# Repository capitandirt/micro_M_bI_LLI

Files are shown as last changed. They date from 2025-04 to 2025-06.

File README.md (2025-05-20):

# *MICROMOUSE WITH USING* C++
  Или же по-старославянски **micro_M_bI_LLI**

## Авторы ПО:

1. [**Capitandirt**](https://github.com/capitandirt)
      
2. [**Denzov**](https://github.com/denzov)

## Главная сводка по micro maze'у
1. Лабиринт N-ого размера (в нашем случае 11x11)
2. Клетка размером 18x18 см
3. Робот ограничен размером 16.8x16.8 см
4. Старт в угловой клетке
5. Финиш в центре

## Основа робота
Конструктив робота взят с [ukrmars](https://github.com/ukmars/ukmarsbot/tree/master)

## Основы терминологии проекта
### Всё, что связано с обозначением передвижения в клетке
| Термин | Что имеется в виду |
|---|---|
| Direction | Направление стороны (nort, west, south, east), в которую совершится действие в лабиринте. |
| Primitive | Обозначает абстрактное действие поворота или движения в клетке лабиринта. Отличает от direction его относительностью от робота. |
| Smart (Циклограмма) | Обозначает действие поворота или движения в клетке лабиринта. Отличает от primitive конкретной реализацией. |
### Хранение данных на МК
#### class Maze
*О том, как представлено хранение лабиринта в памяти посредством структуры RawCellStore.*
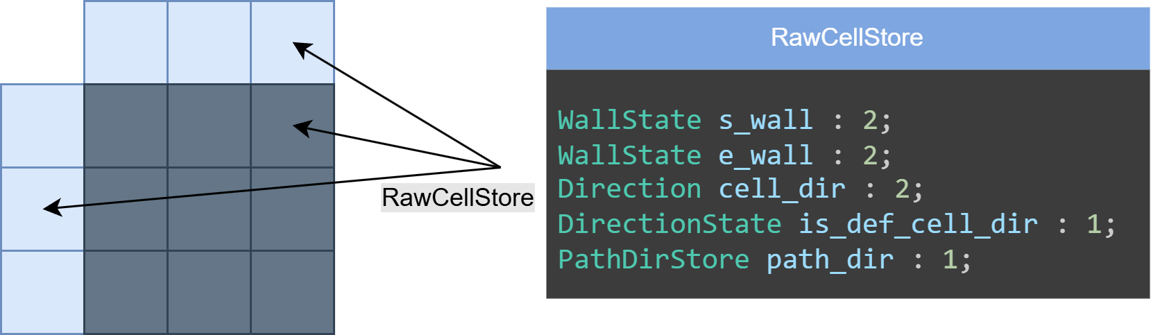
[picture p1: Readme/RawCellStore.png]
RawCellStore

Элемент ячейки общего буффера ```_cell_blocks[MAZE_MEM_SIZE]``` — ```RawCellStore```, занимает 1 байт. Таким образом ```_cell_blocks``` размером MAZE_MEM_SIZE байт. Значение ```MAZE_MEM_SIZE``` определяется размером (N) лабиринта, однако не равно N. Если быть точным ```MAZE_MEM_SIZE = Nx2 + NxN```. Здесь ```NxN``` — "основные" ячейки лабиринта (отмечены темным на картинке), ```Nx2``` — "побочные" или, можно сказать, "фантомные" (отмечены ярко голубым); такие побочные ячейки необходимы, чтобы задавать боковые (западные и северные) стороны лабиринта.
Для того, чтобы понять, что здесь происходит, рассмотрим структуру RawCellStore с битовыми полями:
  1. *s_/e_wall*. Для построения всего лабиринта необходимо лишь сохранять состояние (```HI, LO```) южной и восточной стенки *клетки*.
  2. *cell_dir*. Это битовое поле отвечает за хранение направлений в итоговом пути для лабиринта в каждой ячейке.
  3. *is_def_cell_dir*. Поле отвечает определено ли *cell_dir*.
  4. *path_dir*. Поле отвечает за хранение направлений утогового пути решенного лабиринта. Есть нюанс: все битовые поля, исключая ```path_dir```, занимают 7 бит, однако для хранения Direction необходимо 2 бита (4 направления). Чтобы RawCellStore занимал не более байта, пришлось делать трюк: итогове значение ```path_dir``` складывается от 2 элементов буффера ```_cell_blocks```, как бы разделясь на старшую и младщую часть.

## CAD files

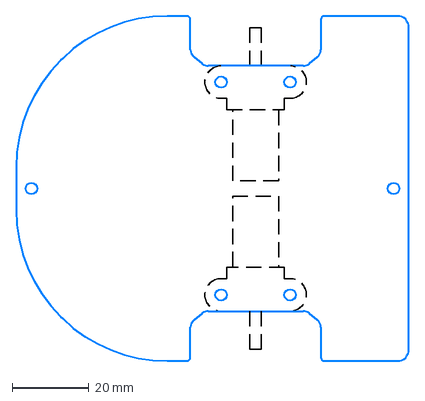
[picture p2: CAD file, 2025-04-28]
Board/main/out/board_contour.dxf
102.5 x 90.0 mm

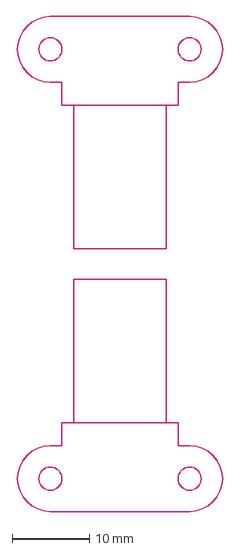
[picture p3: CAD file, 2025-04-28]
Board/main/out/board_contour_for_motors.dxf
26.5 x 64.0 mm

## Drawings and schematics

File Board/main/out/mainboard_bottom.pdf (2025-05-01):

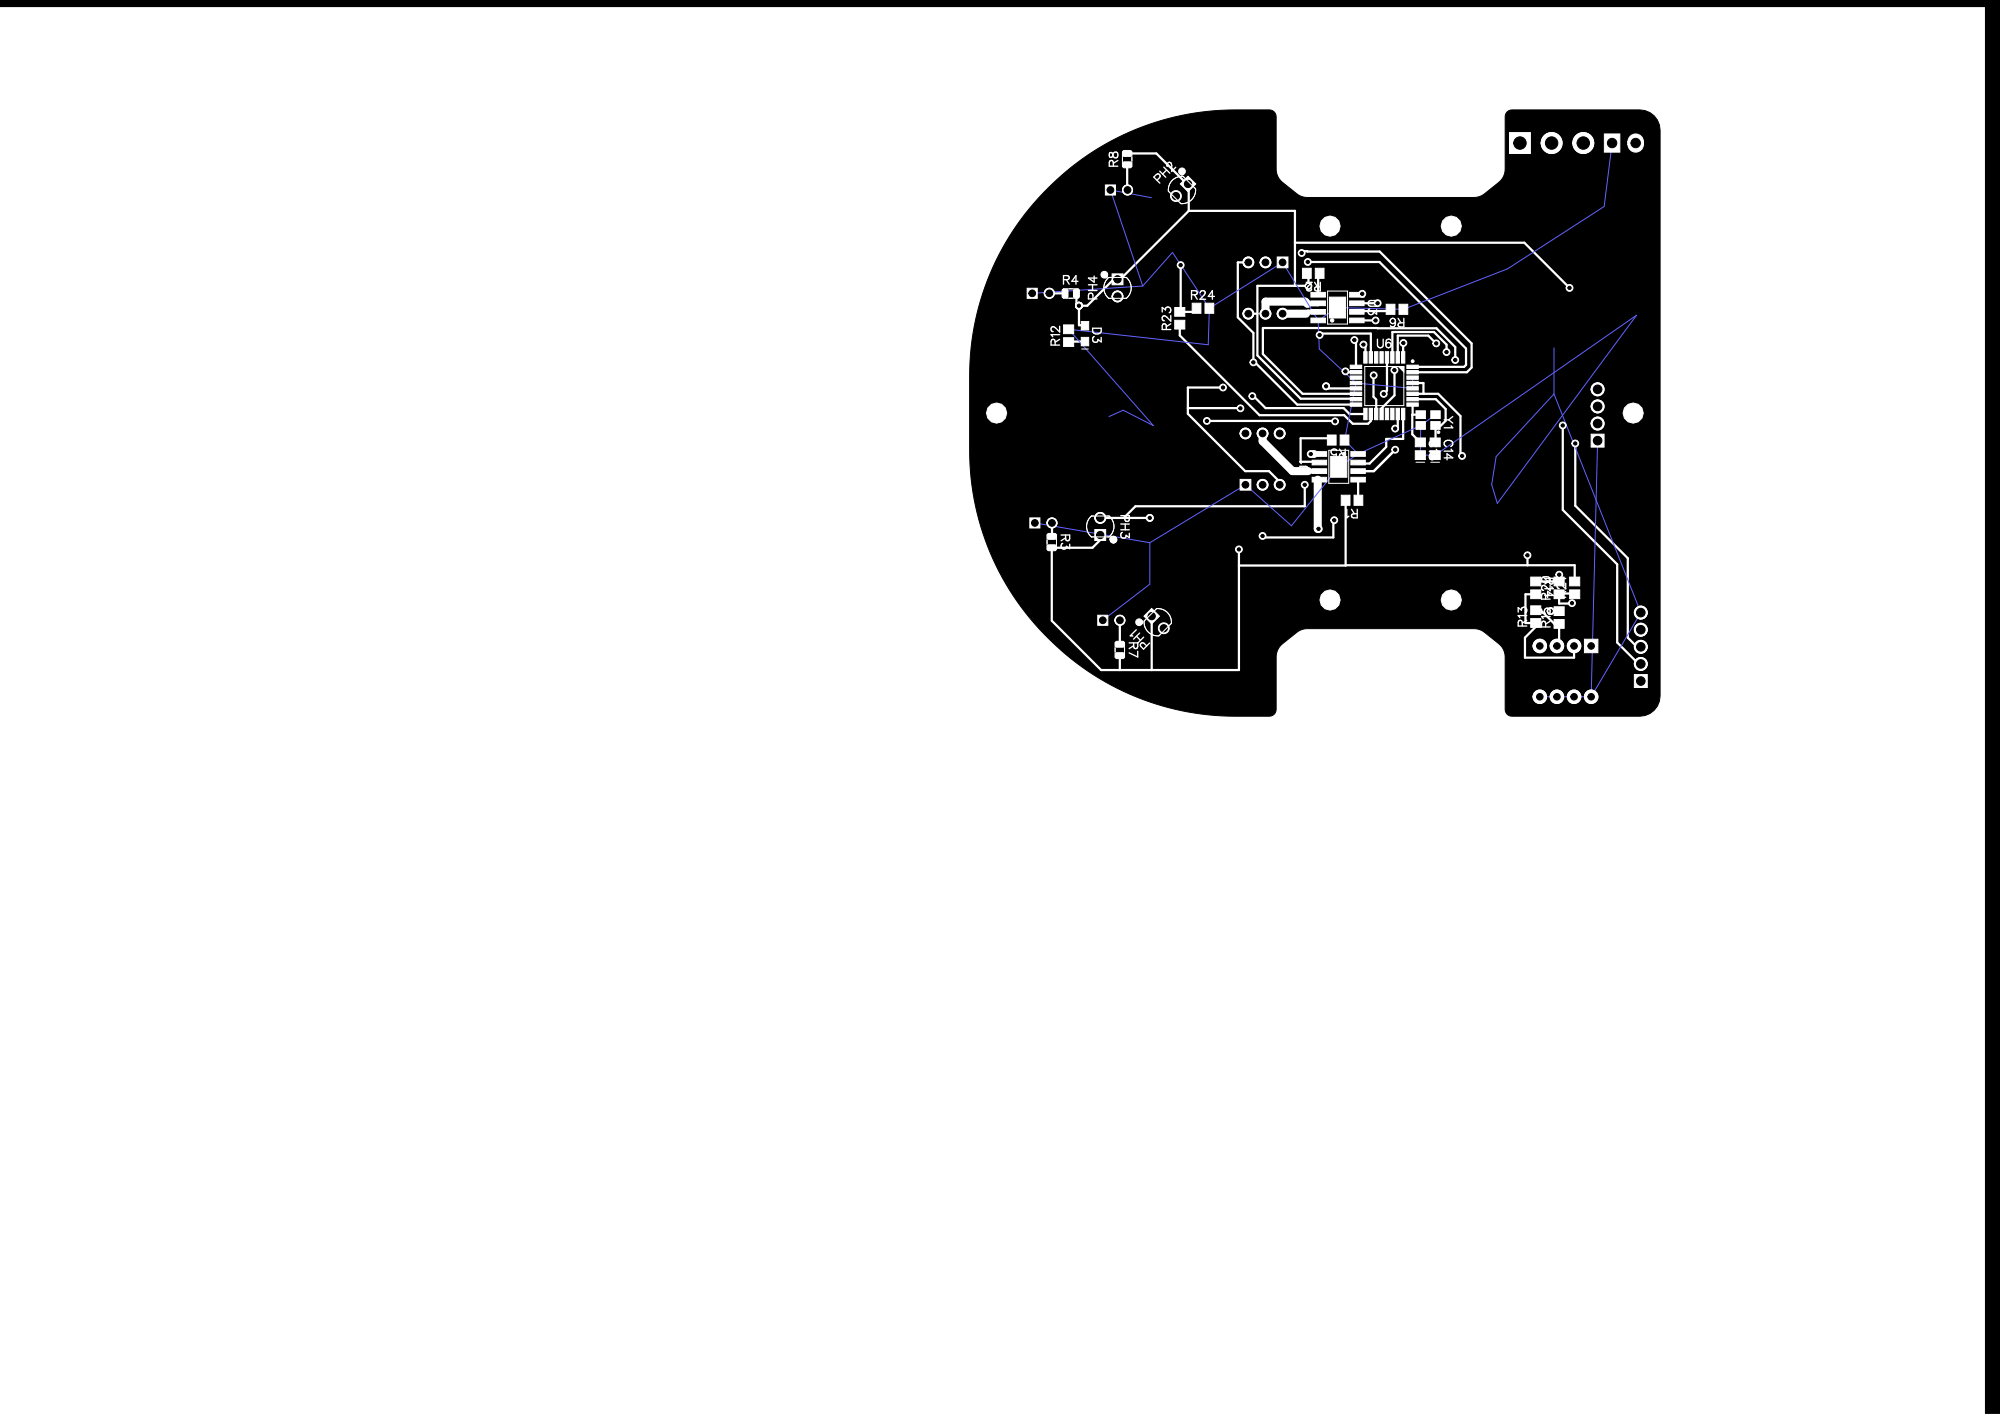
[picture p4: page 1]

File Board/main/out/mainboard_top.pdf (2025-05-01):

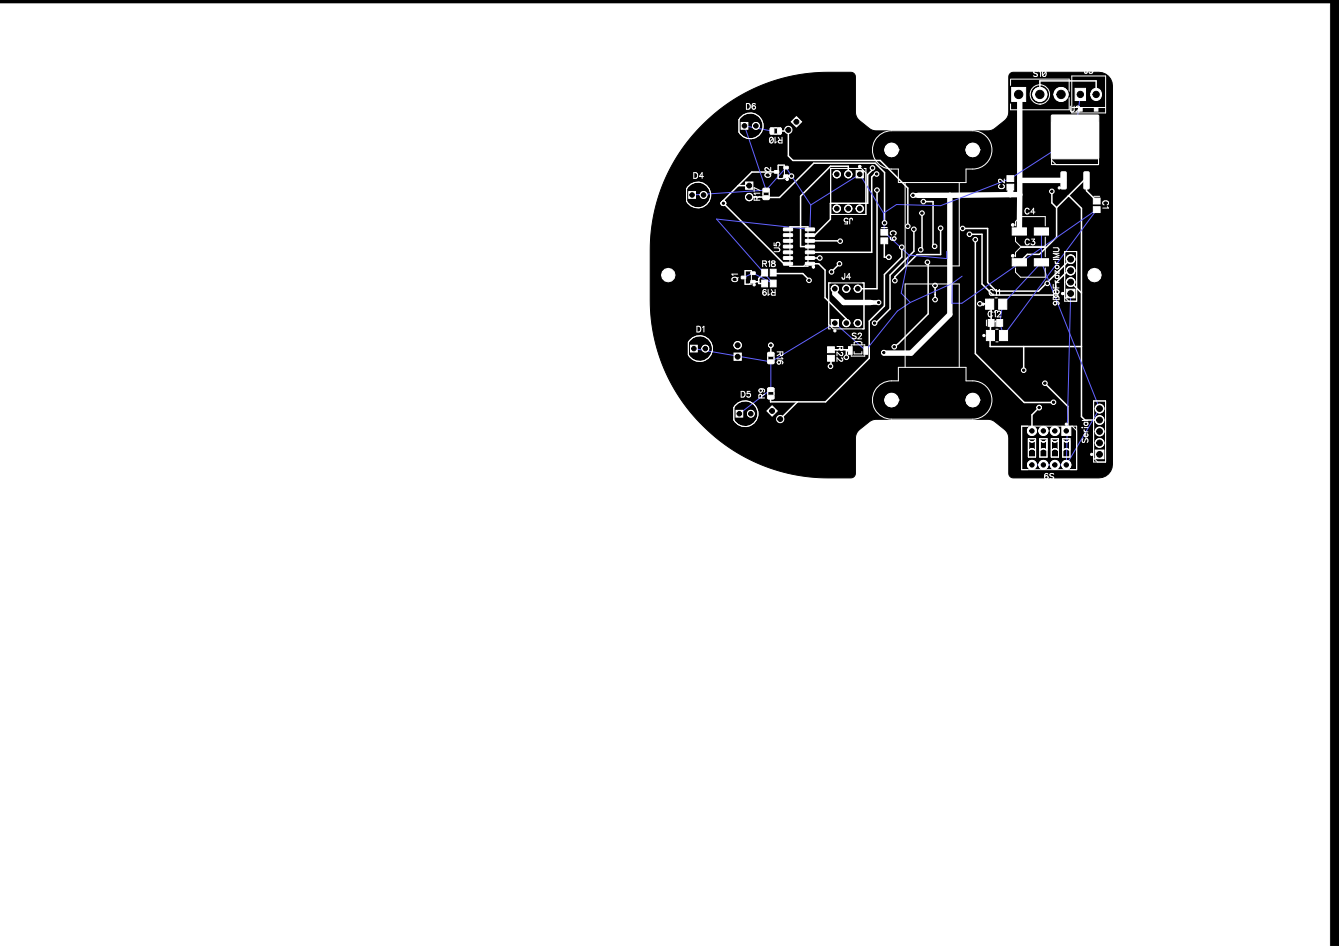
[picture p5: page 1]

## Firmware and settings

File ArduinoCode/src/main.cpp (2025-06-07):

#include <Arduino.h>
#include "Devices.h"
#include "DevicesMethods.h"

void setup()
{
    DEVICES::TEST::SET_SERIAL();
    DEVICES::INIT();

    delay(25); // ставлю delay чтобы датчики успели прочитать значение хотя бы раз
    optocoupler.setStaticError();
}

void loop(){
    static uint32_t last_time = 0;
    while(micros() - last_time < Ts_us)
        ;
    last_time = micros();
    
    DEVICES::TICK(last_time / 1000);

    cycloWorker.doCyclogram();
    robot.stateMachine();
    cycloWorker.tryComplete();
}

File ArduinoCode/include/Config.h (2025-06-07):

#ifndef _CONFIG_H_
#define _CONFIG_H_

/*==GLOBAL SERIAL SHUT DEFINE BEGIN==*/
#define GLOBAL_OUTPUT 0
#if GLOBAL_OUTPUT

#define PRINT(x) Serial.print(x)
#define PRINTLN(x) Serial.println(x)

#else

#define PRINT(x)
#define PRINTLN(x)

#endif
/*==GLOBAL SERIAL SHUT DEFINE END==*/

/*==UTILITY DEFINES BEGIN==*/
#define MAX_ANALOG_VALUE static_cast<int32_t>(1023)
#define HALF(x)  ((x) / 2)
/*==UITILITY DEFINES END==*/

/*==FREQUENCY DISCRETIZATION BEGIN==*/
#define Ts_us 10000 // 0 < Ts_us <= 10000
#define Ts_s (Ts_us / 1000000.0)
/*==FREQUENCY DISCRETIZATION END==*/

/*==ENCODER CONNECTION PINS BEGIN==*/
#define LEFT_CLK_A_PIN 2
#define LEFT_B_PIN 4
#define LEFT_ENC_DIR -1

#define RIGHT_CLK_A_PIN 3
#define RIGHT_B_PIN 5
#define RIGHT_ENC_DIR 1
/*==ENCODER CONNECTION PINS END==*/

/*==ROBOT PARAMS BEGIN==*/
#define ROBOT_WIDTH 0.072f
#define WHEEL_RADIUS 0.01725f
/*==ROBOT PARAMS END*/

/*==WHEELS PARAMS BEGIN==*/
#define ENC_PPR 48
#define GEAR_RATIO 30
#define TICK2RAD (2.f * M_PI / (ENC_PPR * GEAR_RATIO))
/*==WHEELS PARAMS END==*/

/*==MOTOR PINS BEGIN==*/
#define LEFT_MOTOR_DIR 7
#define LEFT_MOTOR_PWM 9
#define LEFT_MOTOR_POLARITY 1

#define RIGHT_MOTOR_DIR 8
#define RIGHT_MOTOR_PWM 10
#define RIGHT_MOTOR_POLARITY 0
/*==MOTOR PINS END==*/

/*==FUNCTIONAL SELECTOR BEGIN==*/
#define INDICATOR_LED_PIN (6)
#define FUNCTION_PIN A6
/*==FUNCTIONAL SELECTOR END==*/

/*==W MOTOT PIREG BEGIN==*/
#define W_K_MOTOR (6 / 1.5) //он выдаёт примерно 6.5 рад/с на 1.5 Волта
#define W_T_MOTOR 0.15
#define W_T_u (2 * Ts_s)

#define W_KP (0.4f) // Kp = K
#define W_KI (W_KP / 0.05f) // Ki = K / T
/*==W MOTOT PIREG END==*/

/*==MAZE BEGIN==*/
// MY MAZE STRUCT
// for exapmle, let's take maze 3x3:
//        X - a x i s 
//      Y      === === ===
//      |     | 0 | 1 | 2 |
//      a  === === === ===
//      x | 3 | 4 | 5 | 6 |
//      i  === === === ===
//      s | 7 | 8 | 9 | 10|
//         === === === ===
//        | 11| 12| 13| 14|
//         === === === ===
// here 0, 1, 2, 3, 7, 11 cells are utility. important for west and north fronts of maze
// total number of cells are 15, but informal numbers of cells are 9 (3x3)

#define MAZE_SIDE_LENGTH 11

#define MAZE_SIDE_LENGTH_ADD_ONE (MAZE_SIDE_LENGTH + 1)
#define MAZE_TOTAL_SIZE (MAZE_SIDE_LENGTH * 2 + MAZE_SIDE_LENGTH * MAZE_SIDE_LENGTH)
#define MAZE_MEM_SIZE (((MAZE_SIDE_LENGTH + MAZE_SIDE_LENGTH) + MAZE_SIDE_LENGTH * MAZE_SIDE_LENGTH))

#define MAZE_PATH_SIZE ((MAZE_TOTAL_SIZE - (MAZE_TOTAL_SIZE % 2)))
/*==MAZE END==*/

/*==QUEUE BEGIN==*/
#define MAX_SIZE_QUEUE (MAZE_SIDE_LENGTH * 4)
/*==QUEUE END*/


/*==ROBOT START PLACE BEGIN==*/
#define START_ROBOT_COORDS {0, 0}
/*==ROBOT START PLACE END==*/


/*==ROBOT FINISH PLACE BEGIN==*/
#define FINISH_ROBOT_COORDS_X (2)
#define FINISH_ROBOT_COORDS_Y (2)

#define FINISH_ROBOT_COORDS {FINISH_ROBOT_COORDS_X, FINISH_ROBOT_COORDS_Y}
/*==ROBOT FINISH PLACE END==*/

/*==CHECK TEST'S CORRECT OUTPUT BEGIN==*/
/*
---[ IN TEST CYCLOGRAMS: 
    \--Primitive:
        | BLANK FORWARD LEFT RIGHT STOP 
    \--Smarts: 
        | IDLE FWD1 SS90SL SS90SR STOP
    ]
---[ IN TEST BFS PATH EQUAL:
    \--| S E N E E E E S S W W S E S E S
    ]
---[ IN TEST CONVERT_PATH_TO_CYCLOGRAM:
    \--|
    IP180 FWD_HALF SS90EL SS90EL SS90ER FWD1 FWD1 FWD1 SS90ER FWD1 SS90ER FWD1 SS90EL SS90EL SS90ER SS90EL SS90ER FWD_HALF STOP
    ]
*/
/*==CHECK TEST'S CORRECT OUTPUT END==*/

/*==OPTOCOUPLER BEGIN==*/
#define OPTOCOUPLER_EMITERS_A (11)
#define OPTOCOUPLER_EMITERS_B (12)

#define OPTOCOUPLER_SENSOR_0 (14)
#define OPTOCOUPLER_SENSOR_1 (15)
#define OPTOCOUPLER_SENSOR_2 (16)
#define OPTOCOUPLER_SENSOR_3 (17)
#define OPTOCOUPLER_SENSOR_4 (18)

#define OPTOCOUPLER_SENSE_ERROR (35)
#define OPTOCOUPLER_SENSE_THRESHOLD_LEFT (50)
#define OPTOCOUPLER_SENSE_THRESHOLD_FWD_L (40)
#define OPTOCOUPLER_SENSE_THRESHOLD_FWD_R (40)
#define OPTOCOUPLER_SENSE_THRESHOLD_RIGHT (50)
/*==OPTOCOUPLER END==*/

/*==BATTERY BEGIN==*/
#define BATTERY_PIN (A7)
/*==BATTERY END==*/

#endif // !_CONFIG_H_

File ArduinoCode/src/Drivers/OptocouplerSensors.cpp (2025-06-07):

#include "Drivers/OptocouplerSensors.h"

void OptocouplerSensors::init(){
    bitClear(ADCSRA, ADPS0);
    bitClear(ADCSRA, ADPS1);
    bitSet(ADCSRA, ADPS2);

    pinMode(EMITERS_FWD, OUTPUT);
    pinMode(EMITERS_SIDE, OUTPUT);
    pinMode(REC_RIGHT, INPUT);
    pinMode(REC_LEFT, INPUT);
    pinMode(REC_FWD_LEFT, INPUT);
    pinMode(REC_FWD_RIGHT, INPUT);
}

void OptocouplerSensors::tick(){
    // dark read
    static int16_t cur_dark_right = 0;
    cur_dark_right = analogRead(REC_RIGHT);

    if(abs(cur_dark_right - dark_sense.right) < 100){
        dark_sense.right = cur_dark_right;
    }

    dark_sense.left      = analogRead(REC_LEFT);
    dark_sense.forward_l = analogRead(REC_FWD_LEFT);
    dark_sense.forward_r = analogRead(REC_FWD_RIGHT);

    digitalWrite(EMITERS_FWD, 1);
    digitalWrite(EMITERS_SIDE, 1);

    delayMicroseconds(50);

    // light read
    CAN_GET_SENSE = 0;

    // _sense[OptocouplerSense::From::RIGHT] += 
    //     (analogRead(REC_RIGHT) - dark_sense.right - _sense[OptocouplerSense::From::RIGHT]) * K_F;

    // _sense[OptocouplerSense::From::LEFT] +=
    //     (analogRead(REC_LEFT) - dark_sense.left - _sense[OptocouplerSense::From::LEFT]) * K_F;

    // _sense[OptocouplerSense::From::FORWARD_L] +=
    //     (analogRead(REC_FWD_LEFT)  - dark_sense.forward_l - _sense[OptocouplerSense::From::FORWARD_L]) * K_F;

    // _sense[OptocouplerSense::From::FORWARD_R] +=
    //     (analogRead(REC_FWD_RIGHT) - dark_sense.forward_r - _sense[OptocouplerSense::From::FORWARD_R]) * K_F;

    _sense[OptocouplerSense::From::RIGHT] = analogRead(REC_RIGHT) - dark_sense.right;
    _sense[OptocouplerSense::From::LEFT]  = analogRead(REC_LEFT)  - dark_sense.left;

    _sense[OptocouplerSense::From::FORWARD_L] = analogRead(REC_FWD_LEFT)  - dark_sense.forward_l;
    _sense[OptocouplerSense::From::FORWARD_R] = analogRead(REC_FWD_RIGHT) - dark_sense.forward_r;

    CAN_GET_SENSE = 1;

    digitalWrite(EMITERS_FWD, 0);
    digitalWrite(EMITERS_SIDE, 0);
}

void OptocouplerSensors::calc(){
    calc_sense_mask();
    calc_relative_cell();
}

Sense_t OptocouplerSensors::getSense() const{
    while(!CAN_GET_SENSE)
        ;

    return _sense.get();
}

Cell OptocouplerSensors::getRelativeCell() const{
    return _relative_cell;
}
Cell OptocouplerSensors::getCell(Direction robot_dir) const{
    Cell cell_from_sense = inDir(_relative_cell, robot_dir);

    return cell_from_sense;
}

void OptocouplerSensors::printAbsCell() const{
    Serial.print((int)_relative_cell.north_wall);
    Serial.print(" ");
    Serial.print((int)_relative_cell.east_wall);
    Serial.print(" ");
    Serial.print((int)_relative_cell.south_wall);
    Serial.print(" ");
    Serial.println((int)_relative_cell.west_wall);
}

void OptocouplerSensors::printMask() const{
    Serial.println( String(_sense_mask.left) + " " + 
                    String(_sense_mask.forward_l) + " " +
                    String(_sense_mask.forward_r) + " " + 
                    String(_sense_mask.right));
}

void OptocouplerSensors::printSense() const{
    while (!CAN_GET_SENSE)
        ;    

    Serial.println( String(_sense.get().left) + " " + 
                    String(_sense.get().forward_l) + " " +
                    String(_sense.get().forward_r) + " " + 
                    String(_sense.get().right));
}

void OptocouplerSensors::calc_sense_mask(){
    _sense_mask.forward_l = _sense[OptocouplerSense::From::FORWARD_L] > SENSE_THRESHOLD_FWD_L;
    _sense_mask.forward_r = _sense[OptocouplerSense::From::FORWARD_R] > SENSE_THRESHOLD_FWD_R;
    _sense_mask.left      = _sense[OptocouplerSense::From::LEFT] > SENSE_THRESHOLD_LEFT;
    _sense_mask.right     = _sense[OptocouplerSense::From::RIGHT] > SENSE_THRESHOLD_RIGHT;
}

void OptocouplerSensors::calc_relative_cell(){
    _relative_cell.north_wall = toWallState(_sense_mask.forward_l || _sense_mask.forward_r);
    _relative_cell.east_wall  = toWallState(_sense_mask.right);
    _relative_cell.west_wall  = toWallState(_sense_mask.left);
    _relative_cell.south_wall = toWallState(false);
}

void OptocouplerSensors::setStaticError()
{
    _static_err = _sense.get().right - _sense.get().left;
}
int16_t OptocouplerSensors::getStaticError() const
{
    return _static_err;
}


int16_t OptocouplerSensors::getLeftTreshold() const
{
    return SENSE_THRESHOLD_LEFT; 
}

int16_t OptocouplerSensors::getRightTreshold() const
{
    return SENSE_THRESHOLD_RIGHT; 
}

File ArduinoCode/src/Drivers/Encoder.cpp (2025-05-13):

#include "Drivers/Encoder.h"

void Encoder::init()
{
    pinMode(CLK_A_PIN, INPUT);
    pinMode(B_PIN, INPUT);

    noInterrupts();
    attachInterrupt(
        digitalPinToInterrupt(CLK_A_PIN),
        ISR,
        CHANGE
    );

    _ett[0b00][0b01] = ENC_DIR;
    _ett[0b01][0b11] = ENC_DIR;
    _ett[0b11][0b10] = ENC_DIR;
    _ett[0b10][0b00] = ENC_DIR;
    
    _ett[0b00][0b10] = -ENC_DIR;
    _ett[0b10][0b11] = -ENC_DIR;
    _ett[0b11][0b01] = -ENC_DIR;
    _ett[0b01][0b00] = -ENC_DIR;
    
    interrupts();
}

void Encoder::tick()
{
    noInterrupts();
    const int counter_inc = _counter;
    _counter = 0;
    interrupts();

    _dphi = counter_inc * TICK2RAD;
    _phi += _dphi;
}

void Encoder::isrCallback()
{
    const uint8_t B = digitalRead(B_PIN);
    const uint8_t CLK_A = digitalRead(CLK_A_PIN);
    const uint8_t A = CLK_A ^ B;
    const uint8_t enc = (A << 1) | B;

    _counter += _ett[_enc_old][enc];
    _enc_old = enc;
}

float Encoder::getPhi() const{
    return _phi;
}

float Encoder::getDPhi() const{
    return _dphi;
}

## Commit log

2025-04-16 первый коммит
    [M_bI_LLI_plate.PrjPcb]
2025-04-16 упс, вот теперь первы коммит
    [PCB1.PcbDoc]
2025-04-18 до конца соединили коды, сделали базу фладфила
2025-04-19 added convesion from maze ind to vec2 and in reverse
    [Config.h, Maze.cpp]
2025-04-20 added template of a plate
    [M_bI_LLI_plate.PrjPcb, PCB1.PcbDoc]
2025-04-23 completed schematic, started 3d plate view
2025-04-23 added prototype of mouse in 3d
2025-04-23 added the hole for the travois (тип `-` волокуша)
2025-04-24 minor changes in plate
2025-04-24 restructuring boards directories
    [board_contour.dxf]
2025-04-24 modified Board/.gitignore
2025-04-25 окончательное преобразование пути в поисковые циклограммы
2025-04-26 added timer interrupt fo tick devices
2025-04-26 changed getting robot primitives, timer interrupts are debugging now
2025-04-26 added pcb
2025-04-28 added optocoupler sense & worked with board
    [board_contour.dxf, board_contour_for_motors.dxf]
2025-04-28 added tim2 handler. completed interrupts. first realization of tick in optocoupler
2025-04-29 completed class Optocoupler. Flood fill works in theory. Changed odometry: getting maze coords and dirs from flood fill funcs
2025-04-29 board in process
2025-04-30 сделал первичную разводку платы
2025-04-30 мелкие фиксы
2025-04-30 добавил провреку на пройденную клетку в rawCellStore. не рабочий код - floodfill не аърабоатет
2025-05-01 fixed errors in pcb board
2025-05-01 pcb minor fix
2025-05-01 pcb minor fix 2
2025-05-02 исправил одометрию, сделал проверку на 135 градусов
    [Odometry.cpp]
2025-05-07 сделал первую версию регулятора по датчикам
2025-05-07 РАБОЧИЙ КОД ФЛАДФИЛА
    +рабочий регулятор по датчикам
2025-05-08 not workable back handler
    [Config.h, CycloStore.cpp, Cyclograms.h]
2025-05-09 нерабочий коммит, переход для мержа
2025-05-09 я написал (кажется) FWD_X
2025-05-10 промежуточны коммит, см описание
    циклограммы в отдельную папку, пару новых циклограмм, удалены следы плохого решения на FWD_X
2025-05-10 Сделал десяток новых циклограмм,
2025-05-10 напичал TO_DD90S, продолжил писать toSmart, но недописал
    также придумал и описал архитектуру toSmart, на которую перепишу её позже
2025-05-12 Продолжил писать convertToSmart, написал entryHandler
2025-05-14 начал писать RepeatHandler
2025-05-14 написал repeatActionHandler, ExitHandler не работает
2025-05-15 completed button handler in function selector. started startExplorer in robot
2025-05-16 повысили точность робота, починил пару циклограмм
2025-05-18 мерж с изменением Макса
2025-05-21 предварительно работает convertToSmart
    повернул диоды в плате
2025-05-23 не устранена проблема в TO_DIA_X
2025-05-30 добавлен драйвер батареи
2025-05-30 незаконченные изменения
2025-05-30 регулятор по глобальному углу сделал (везде кроме search)
2025-05-30 battery in process
2025-05-30 добавил регулятор по углу в сёрч
2025-05-30 регулятор работает, но он отключён, т.к. он всё ломает
2025-05-30 накостылил ширину робота, добавил отдельную скорость для смартов
2025-05-30 РАБОЧИЙ КОММИТ ДЛЯ СОРЕВ
2025-05-31 максимально быстрый сёрч без смартов
2025-05-31 сделал шаблоны
2025-05-31 нерабочие шаблоны, продолжаем работу
2025-05-31 продолжаю добавлять шаблоны
2025-05-31 шаблон почти работает(
2025-06-02 вернул регулятор по углу, но всё также отклюил его
2025-06-04 добавил FunctionSelector, функционал см в .h файле или описание
    теперь можно задать стартовое направление робота (E/S) при помощи слайдера 4 и можно задать, едет он исследовать лабиринт или едет "фастами" по слайдеру 1. После финиша исследования его следующий реж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
2025-06-04 добавил возврат к началу проезда по фастам по кнопке, если он сбился
2025-06-04 подправил циклограммы SS90S и нашёл ошибку в convertToSmart-е, буду исправлять
    [Cyclogram.config.h, Cyclograms.h, main.cpp]
2025-06-05 починил проблему в convertToSmart
2025-06-05 поменяли обработку статуса fast и почти приделал движение вперёд с ускорением
2025-06-06 ускорение на прямых участках работает, но есть проскальзывание
2025-06-06 battery in motor
2025-06-06 замержил батарею
2025-06-06 статическая ошибка на регуляторе оптопар, поддержка батарей
2025-06-06 починил functionSelector
2025-06-07 пытаюсь исправить решение explorer
    [Config.h, CycloStore.cpp, main.cpp]
